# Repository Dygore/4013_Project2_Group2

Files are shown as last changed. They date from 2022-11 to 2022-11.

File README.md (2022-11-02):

# ECEN 4013 Project 2 Group 2

## About
This project is for Group 2's ECEN 4013 project 2, all of the code contained will be documented and cited if needed. The goal of this project is to create a circuit that can transmit IMU and GPS data through 3 means of communication (USB, UHF RF, and SD Card). This Github project will be used to store all of the code architecture, the details of the project are still being finalized and will be updated soon!

## Details
The current plan is to have two seperate circuits based on difficulty. The first circuit will be the main focus with the details contained below, the second circuit details have not been finalized yet.

Micro controller: Raspberry Pi Pico  
GPS: Adafruit Mini GPS PA1010D  
Radio: HC05  
IMU: Adafruit BNO055  
SD Card:  HW-125 SPI Micro SD Board  
Battery: LP103454  

## References
-https://microcontrollerslab.com/neo-6m-gps-module-raspberry-pi-pico-micropython/

Dylan Gore 10/24/2022

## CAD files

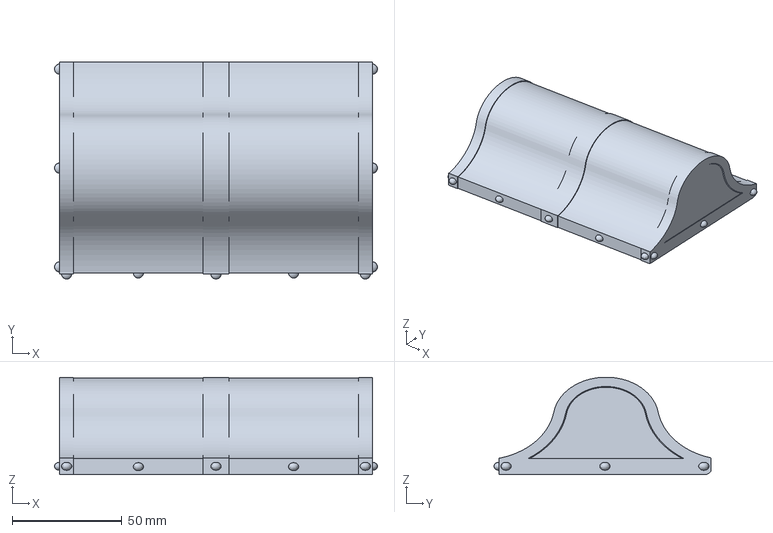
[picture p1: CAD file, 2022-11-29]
3D_Print/Top.3mf
147.3 x 99.0 x 44.5 mm

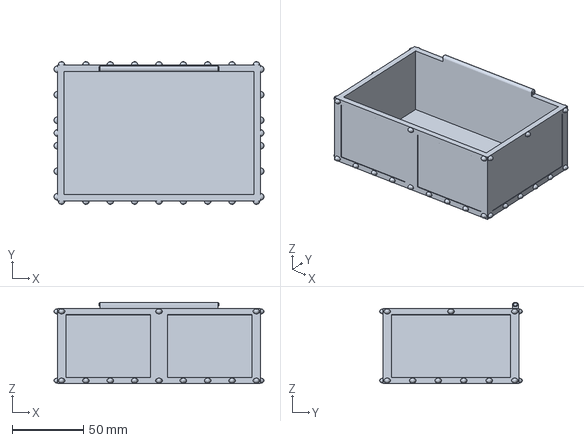
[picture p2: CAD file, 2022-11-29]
3D_Print/Body.3mf
147.3 x 100.1 x 57.1 mm

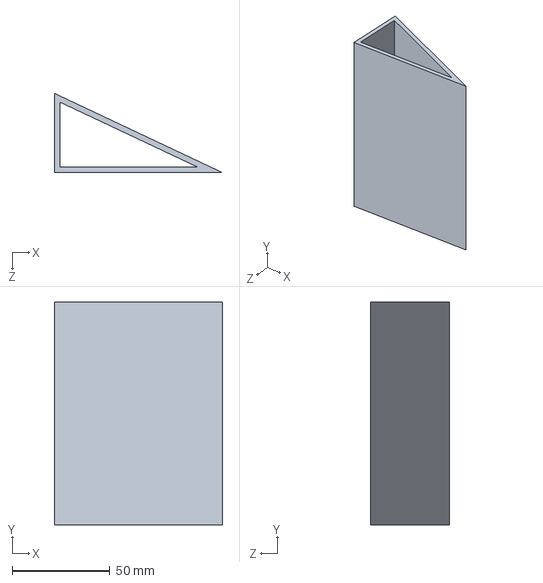
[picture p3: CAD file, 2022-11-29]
3D_Print/Triangle.SLDPRT
86.1 x 114.3 x 40.6 mm

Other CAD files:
3D_Print/Triangle.3mf

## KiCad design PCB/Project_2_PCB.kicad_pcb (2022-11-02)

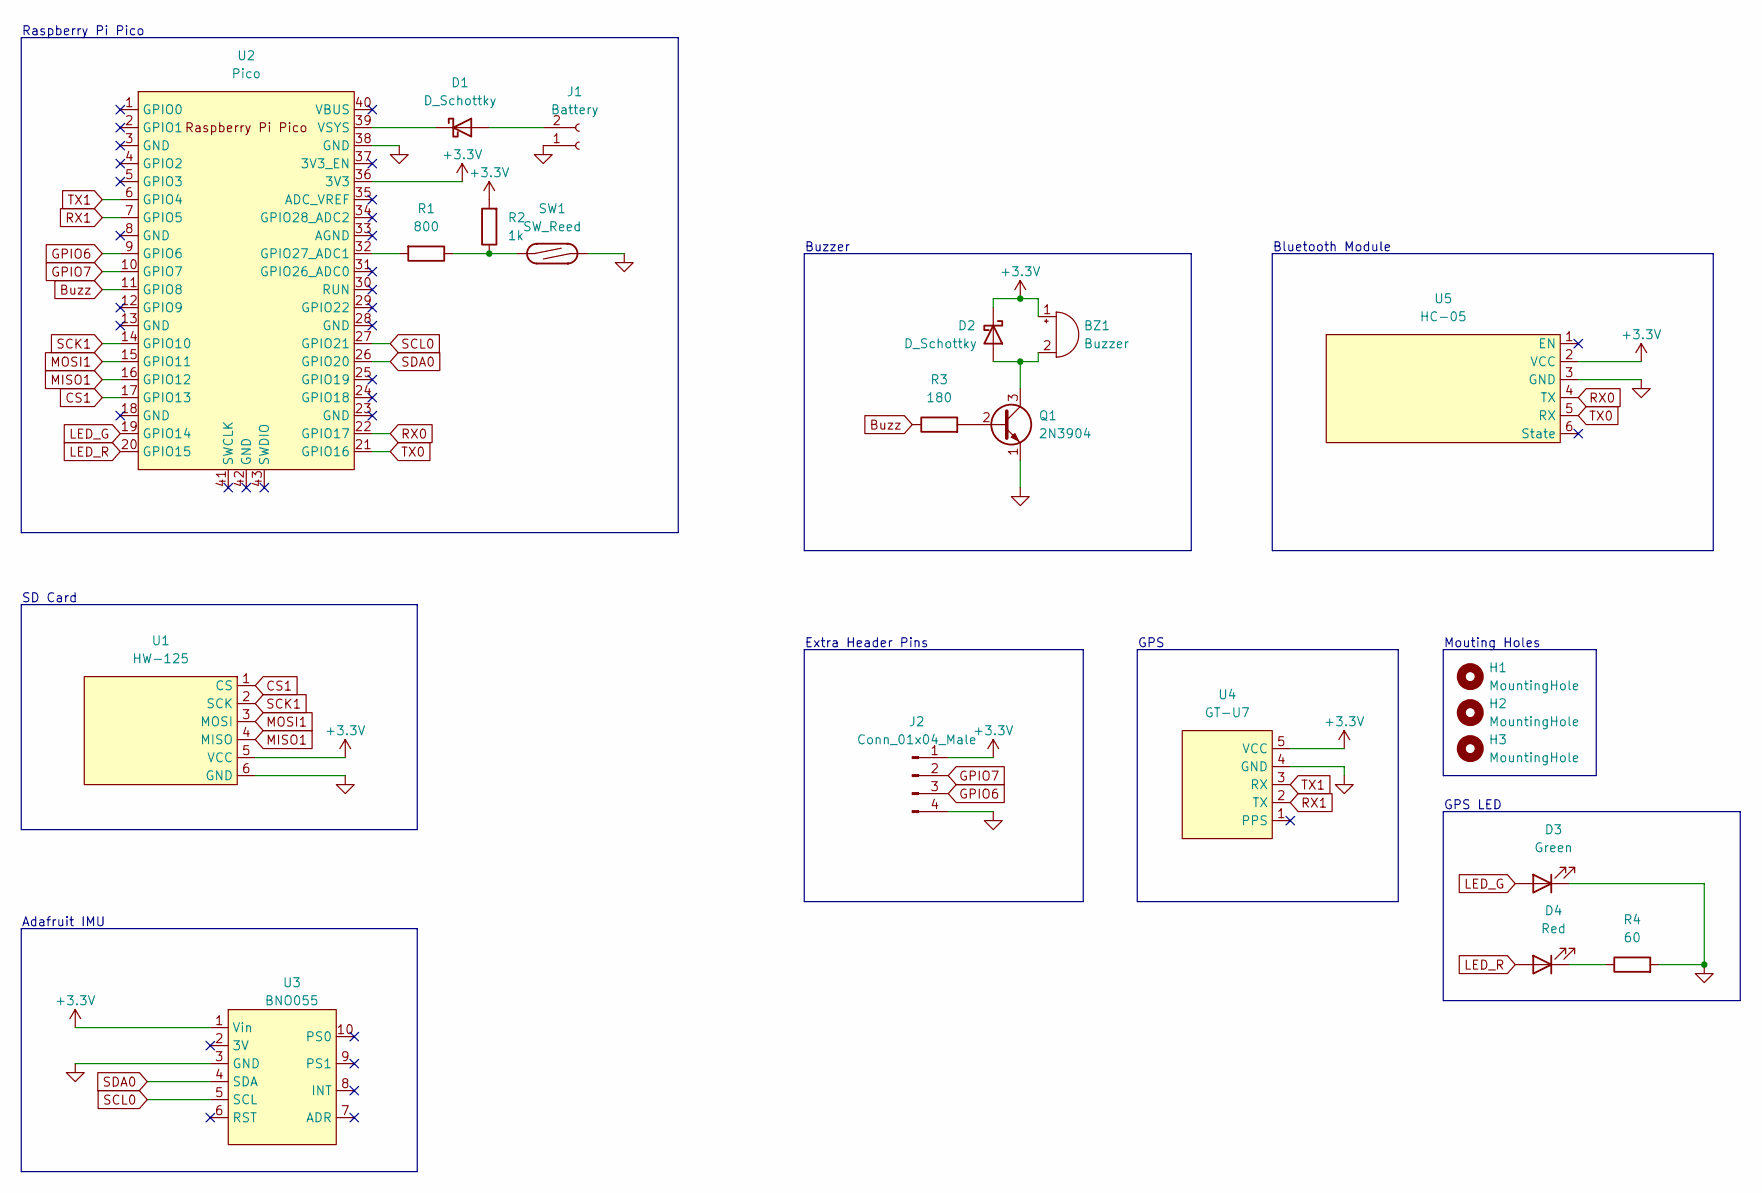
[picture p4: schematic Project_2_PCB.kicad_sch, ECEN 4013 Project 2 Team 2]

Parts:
BZ1: Buzzer; CMT8585397SMTTR
D1, D2: D_Schottky; D_1206_3216Metric
D3: Green; LED_D5.0mm
D4: Red; LED_D5.0mm
H1, H2, H3: MountingHole; MountingHole_4.3mm_M4_Pad_TopBottom
J1: Battery; JST_PH_S2B-PH-K_1x02_P2.00mm_Horizontal
J2: Conn_01x04_Male; PinHeader_1x04_P2.54mm_Vertical
Q1: 2N3904; SOT-23
R1: 800; R_Axial_DIN0207_L6.3mm_D2.5mm_P7.62mm_Horizontal
R2: 1k; R_Axial_DIN0207_L6.3mm_D2.5mm_P7.62mm_Horizontal
R3: 180; R_Axial_DIN0207_L6.3mm_D2.5mm_P7.62mm_Horizontal
R4: 60; R_Axial_DIN0207_L6.3mm_D2.5mm_P7.62mm_Horizontal
SW1: SW_Reed; R_Axial_DIN0207_L6.3mm_D2.5mm_P10.16mm_Horizontal
U1: HW-125
U2: Pico; RPi_Pico_SMD_TH
U3: BNO055
U4: GT-U7
U5: HC-05

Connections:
+3V3: BZ1.1 (-), D2.1 (K), J2.1, R2.2, U1.5 (VCC), U2.36 (3V3), U3.1 (Vin), U4.5 (VCC), U5.2 (VCC)
Buzz: R3.1, U2.11 (GPIO8)
CS1: U1.1 (CS), U2.17 (GPIO13)
GND: D3.1 (K), J1.1, J2.4, Q1.1 (E), R4.2, SW1.2, U1.6 (GND), U2.38 (GND), U3.3 (GND), U4.4 (GND), U5.3 (GND)
GPIO6: J2.3, U2.9 (GPIO6)
GPIO7: J2.2, U2.10 (GPIO7)
LED_G: D3.2 (A), U2.19 (GPIO14)
LED_R: D4.2 (A), U2.20 (GPIO15)
MISO1: U1.4 (MISO), U2.16 (GPIO12)
MOSI1: U1.3 (MOSI), U2.15 (GPIO11)
unnamed: BZ1.2 (+), D2.2 (A), Q1.3 (C)
unnamed: D1.1 (K), U2.39 (VSYS)
unnamed: D1.2 (A), J1.2
unnamed: D4.1 (K), R4.1
unnamed: Q1.2 (B), R3.2
unnamed: R1.1, R2.1, SW1.1
unnamed: R1.2, U2.32 (GPIO27_ADC1)
RX0: U2.22 (GPIO17), U5.4 (TX)
RX1: U2.7 (GPIO5), U4.2 (TX)
SCK1: U1.2 (SCK), U2.14 (GPIO10)
SCL0: U2.27 (GPIO21), U3.5 (SCL)
SDA0: U2.26 (GPIO20), U3.4 (SDA)
TX0: U2.21 (GPIO16), U5.5 (RX)
TX1: U2.6 (GPIO4), U4.3 (RX)

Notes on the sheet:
Extra Header Pins
Raspberry Pi Pico
Bluetooth Module
GPS
Adafruit IMU
Buzzer
GPS LED
Mouting Holes
SD Card

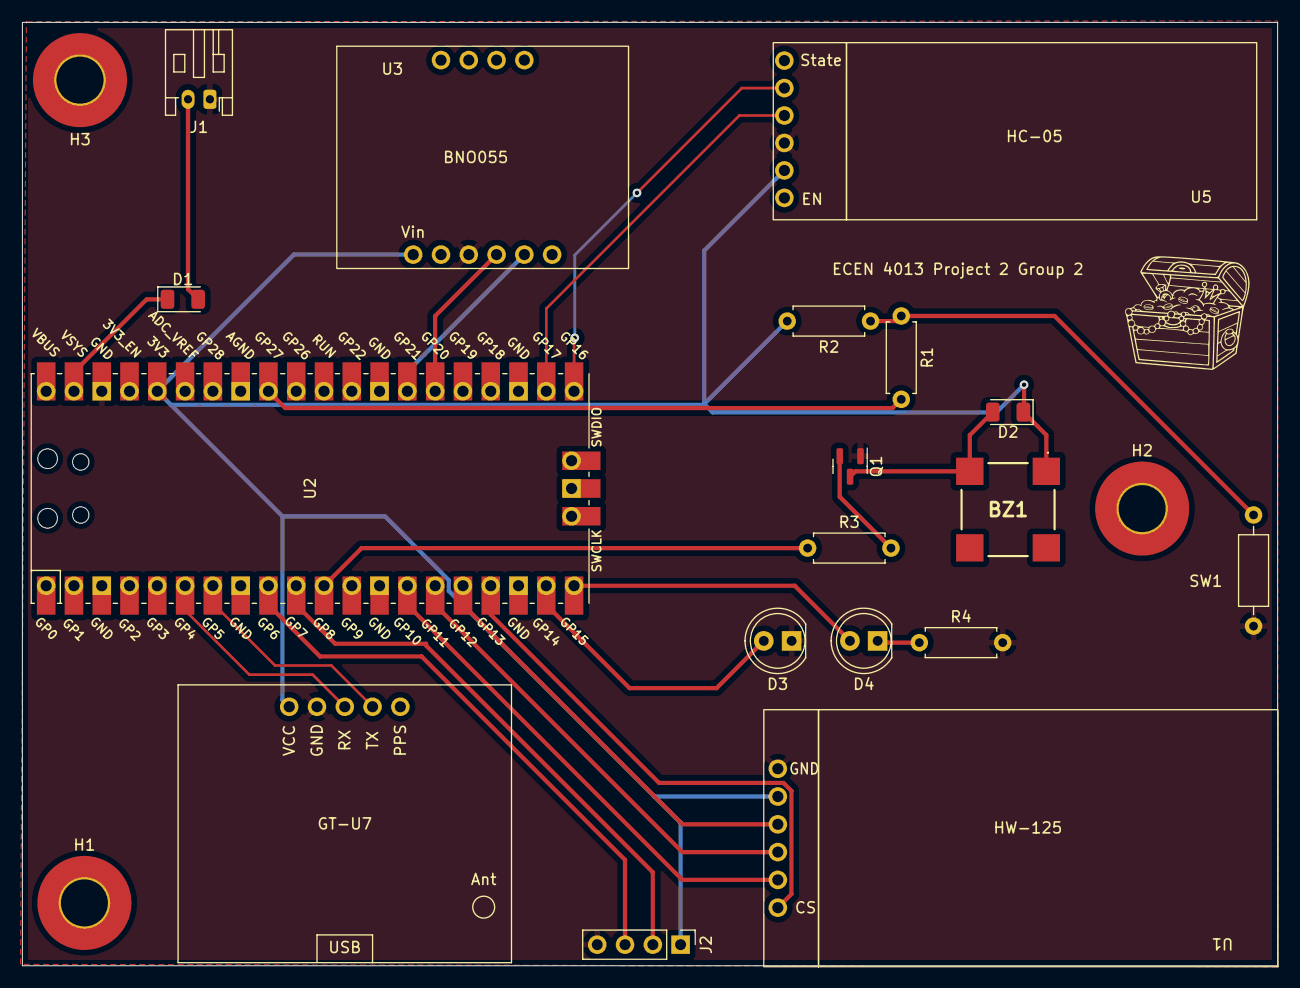
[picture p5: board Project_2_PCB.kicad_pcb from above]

Board: 2 copper layers, 114.7 x 86.2 mm, 21 parts (0 on the bottom side), 24 nets.

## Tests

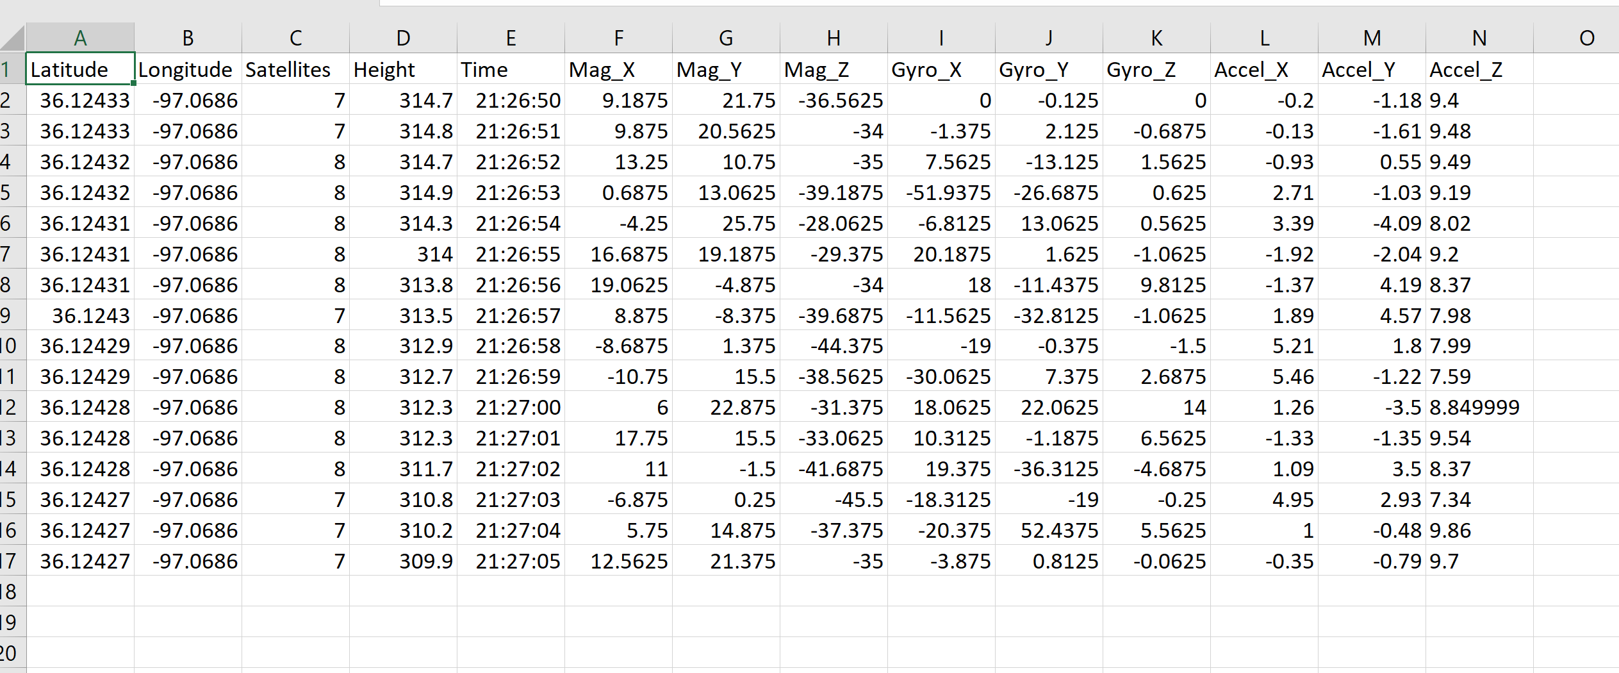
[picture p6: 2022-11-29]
Main/First_Working_GPS_IMU_Test.png

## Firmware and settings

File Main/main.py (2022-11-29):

#-------------------------------Import from Pico-------------------------------
from machine import Pin, UART, I2C, SPI, PWM

#-------------------------------Other Imports-------------------------------
import utime, time
from bno055 import *

import sdcard, uos

#-------------------------------Initialize Serial Communcation-------------------------------
#----------GPS----------
gpsModule = UART(1, baudrate=9600, tx=Pin(4), rx=Pin(5))
#----------Bluetooth UART----------
#----------IMU I2C----------
i2c = I2C(0, scl=Pin(21), sda=Pin(20))
#----------SD Card SPI----------
cs = Pin(13, Pin.OUT)
spi = SPI(1,baudrate=100000,polarity=0,phase=0,bits=8,firstbit=SPI.MSB,sck=Pin(10),mosi=Pin(11),miso=Pin(12))
#-------------------------------Variable Declarations/Initializations-------------------------------
buzzer = PWM(Pin(8))
tones = {
"B0": 31,
"C1": 33,
"CS1": 35,
"D1": 37,
"DS1": 39,
"E1": 41,
"F1": 44,
"FS1": 46,
"G1": 49,
"GS1": 52,
"A1": 55,
"AS1": 58,
"B1": 62,
"C2": 65,
"CS2": 69,
"D2": 73,
"DS2": 78,
"E2": 82,
"F2": 87,
"FS2": 93,
"G2": 98,
"GS2": 104,
"A2": 110,
"AS2": 117,
"B2": 123,
"C3": 131,
"CS3": 139,
"D3": 147,
"DS3": 156,
"E3": 165,
"F3": 175,
"FS3": 185,
"G3": 196,
"GS3": 208,
"A3": 220,
"AS3": 233,
"B3": 247,
"C4": 262,
"CS4": 277,
"D4": 294,
"DS4": 311,
"E4": 330,
"F4": 349,
"FS4": 370,
"G4": 392,
"GS4": 415,
"A4": 440,
"AS4": 466,
"B4": 494,
"C5": 523,
"CS5": 554,
"D5": 587,
"DS5": 622,
"E5": 659,
"F5": 698,
"FS5": 740,
"G5": 784,
"GS5": 831,
"A5": 880,
"AS5": 932,
"B5": 988,
"C6": 1047,
"CS6": 1109,
"D6": 1175,
"DS6": 1245,
"E6": 1319,
"F6": 1397,
"FS6": 1480,
"G6": 1568,
"GS6": 1661,
"A6": 1760,
"AS6": 1865,
"B6": 1976,
"C7": 2093,
"CS7": 2217,
"D7": 2349,
"DS7": 2489,
"E7": 2637,
"F7": 2794,
"FS7": 2960,
"G7": 3136,
"GS7": 3322,
"A7": 3520,
"AS7": 3729,
"B7": 3951,
"C8": 4186,
"CS8": 4435,
"D8": 4699,
"DS8": 4978
}

song = ["E5","D5","C5","D5","E5","E5","E5","P","D5","D5","D5","E5","G5","G5","P","E5","D5","C5","D5","E5","E5","E5","P","E5","D5","D5","E5","D5","C5"]
#----------GPS----------
buff = bytearray(255)
timeout = False
Status = False
latitude = ""
longitude = ""
satellites = ""
HeightGeo = ""
GPStime = ""
ledg = Pin(14, Pin.OUT)
ledr = Pin(15, Pin.OUT)
magnet = Pin(27, Pin.IN)
#----------Bluetooth----------
#----------IMU----------
addr = 0x28
imu = BNO055(i2c)
accel = ""
gyro= ""
mag = ""
data = []

#----------SD Card----------
while True:
    try:
        sd = sdcard.SDCard(spi, cs)

        vfs = uos.VfsFat(sd)
        uos.mount(vfs, "/sd")
        break
    except:
        ledg.value(0)
        ledr.value(1)
    
fields = ['Latitude', 'Longitude', 'Satellites', 'Height', 'Time', 'Mag_X', 'Mag_Y', 'Mag_Z', 'Gyro_X', 'Gyro_Y', 'Gyro_Z', 'Accel_X', 'Accel_Y', 'Accel_Z']
#-------------------------------Define Methods-------------------------------
#----------GPS----------
def getGPSData(gpsModule):
    global Status, latitude, longitude, satellites, GPStime, HeightGeo
    
    while True:
        #Get second line and add it to buffer
        buffer = str(gpsModule.readline())
        
        #Split up buffer using commas
        section = buffer.split(',')
    
        #We only want GPGGA as it contains all the data that is needed for this project
        if (section[0] == "b'$GPGGA" and section[4] != ''):
            latitude = convertToDegree(section[2])
            if (section[3] == 'S'):
                latitude = '-' + latitude
            longitude = convertToDegree(section[4])
            if (section[5] == 'W'):
                longitude = '-' + longitude
            satellites = section[7]
            HeightGeo = section[9]
            GPStime = section[1][0:2] + ":" + section[1][2:4] + ":" + section[1][4:6]
            Status = True
            #Set LED to Signal Found
            ledg.value(1)
            ledr.value(0)
            break
        elif (section[0] == "b'$GPGGA" and section[4] == '') :
            #Set LED to Searching for Signal
            ledg.value(0)
            ledr.value(1)    
        utime.sleep_ms(100)
        
def convertToDegree(RawDegrees):

    RawAsFloat = float(RawDegrees)
    firstdigits = int(RawAsFloat/100) 
    nexttwodigits = RawAsFloat - float(firstdigits*100) 
    
    Converted = float(firstdigits + nexttwodigits/60.0)
    Converted = '{0:.6f}'.format(Converted) 
    return str(Converted)

#----------Bluetooth----------

#----------IMU----------
def getIMUData(imu):
    global mag_tuple, gyro_tuple, accel_tuple

    mag_tuple = ",".join(str(item) for item in imu.mag())
    
    gyro_tuple = ",".join(str(item) for item in imu.gyro())

    accel_tuple = ",".join(str(item) for item in imu.accel())
    
#----------SD Card----------
def sdCard():
    global latitude, longitude, satellites, GPStime, HeightGeo, mag_tuple, gyro_tuple, accel_tuple
    while True:
        try:
            logf = open("/sd/logfile.csv","a")
            logf.write(latitude)
            logf.write(",")
            logf.write(longitude)
            logf.write(",")
            logf.write(satellites)
            logf.write(",")
            logf.write(HeightGeo)
            logf.write(",")
            logf.write(GPStime)
            logf.write(",")
            logf.write(mag_tuple)
            logf.write(",")
            logf.write(gyro_tuple)
            logf.write(",")
            logf.write(accel_tuple)
            logf.write("\r\n")
            logf.close()
            break
        except:
            ledg.value(0)
            ledr.value(1)

#----------Buzz----------
def playtone(frequency):
    buzzer.duty_u16(1000)
    buzzer.freq(frequency)

def bequiet():
    buzzer.duty_u16(0)

def playsong(mysong):
    for i in range(len(mysong)):
        if (mysong[i] == "P"):
            bequiet()
        else:
            playtone(tones[mysong[i]])
        utime.sleep_ms(300)
    bequiet()
    
#-------------------------------Main Methods-------------------------------
logf = open("/sd/logfile.csv","a")
try:
    logf.write("Latitude")
    logf.write(",")
    logf.write("Longitude")
    logf.write(",")
    logf.write("Satellites")
    logf.write(",")
    logf.write("HeightGeo")
    logf.write(",")
    logf.write("GPS Time")
    logf.write(",")
    logf.write("Mag_X")
    logf.write(",")
    logf.write("Mag_Y")
    logf.write(",")
    logf.write("Mag_Z")
    logf.write(",")
    logf.write("Gryo_X")
    logf.write(",")
    logf.write("Gyro_Y")
    logf.write(",")
    logf.write("Gyro_Z")
    logf.write(",")
    logf.write("Accel_X")
    logf.write(",")
    logf.write("Accel_Y")
    logf.write(",")
    logf.write("Accel_Z")
    logf.write("\r\n")
except OSError:
    print("Sd Full")
logf.close()

while True:
    #Get GPS Data
    getGPSData(gpsModule)
    #Get IMU Data
    getIMUData(imu)
        
    #Output to USB
    if(Status == True):
         print("{"+ latitude + ',' + longitude + ',' + satellites + ',' + HeightGeo + ',' + GPStime + ',' + mag_tuple + ',' + gyro_tuple + ',' + accel_tuple +"\n")   
         Status = False
         
    #SD Card
    sdCard()
    #Output to Bluetooth
    
    if magnet.value() == 0:
        ledg.value(0)
        ledr.value(1)
        playsong(song)
    

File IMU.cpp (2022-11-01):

#include <iostream>
#include <vector>
#include <string>
#include "hardware/i2c.h" //i2c protocol library
#include "pico/stdlib.h" //raspberry pi pico library

#define I2C_PORT i2c0; //GPIO Pins 4 and 5
static int addr = 0x28; // default adafruit address (peripheral)

// Initialize Accelerometer Function
void accel_init(void){
    //check to see that connection is correct
    //should expect the chip to have an ID of 0xA0 or 1010_0000
    sleep_ms(10000); //add short delay to help  BNO055
    uint8_t reg = 0x00;
    uint8_t chipID[1];
    i2c_write_blocking(I2C_PORT, addr, &reg, 1, true); //true: controller maintains control of I2C bus - no stop msg
    i2c_read_blocking(I2C_PORT, addr, chipID, 1, false); //false: controller releases control

    if(chipID[0] != 0xA0){
        while(1){
            printf("Chip ID Not Correct - Check Connection");
            sleep_ms(5000);
        }
    }

    // Use internal oscillator
    uint8_t data[2]; //2 unsigned 8 bit ints
    data[0] = 0x3F; //register addr we want to send
    data[1] = 0x40; //data we want to transmit
    i2c_write_blocking(I2C_PORT, addr, data, 2, true);

    // Reset all interrupt status bits
    data[0] = 0x3F;
    data[1] = 0x01;
    i2c_write_blocking(I2C_PORT, addr, data, 2, true);

    // Configure Power Mode
    data[0] = 0x3E;
    data[1] = 0x00;
    i2c_write_blocking(I2C_PORT, addr, data, 2, true);
    sleep_ms(50);

    // Defaul Axis Configuration
    data[0] = 0x41;
    data[1] = 0x24;
    i2c_write_blocking(I2C_PORT, addr, data, 2, true);

    // Default Axis Signs
    data[0] = 0x42;
    data[1] = 0x00;
    i2c_write_blocking(I2C_PORT, addr, data, 2, true);

    // Set units to m/s^2
    data[0] = 0x3B;
    data[1] = 0b0001000;
    i2c_write_blocking(I2C_PORT, addr, data, 2, true);
    sleep_ms(30);

    // Set operation to acceleration only
    data[0] = 0x3D;
    data[1] = 0x0C;
    i2c_write_blocking(I2C_PORT, addr, data, 2, true);
    sleep_ms(100);

}//end accel_init

int main(){
    //Initizalize STD I/O for printing over serial over USB interface
    stdio_init_all();

    //Configure the I2C Coms
    12c_init(I2C_PORT, 400000); //400kHz
    gpio_set_function(4, GPIO_FUNC_I2C); //SCL - GPIO 4
    gpio_set_function(5, GPIO_FUNC_I2C); //SDA - GPIO 5
    //enable pull-up resistors for SCL and SDA
    gpio_pull_up(4); 
    gpio_pull_up(5);

    //Call accelerometer initialization funct
    accel_init();

    uint8_t accel[6]; // Store data from the 6 acceleration regs
    int16_t accelX, accelY, accelZ; // combined 3 axis data
    float f_accelX, f_accelY, f_accelZ; // float type of accel data
    uint8_t val = 0x08; // start reg addr

    while(1){
        i2c_write_blocking(I2C_PORT, addr, &val, 1, true);
        i2c_read_blocking(I2C_PORT, addr, accel, 6, false);

        accelX = ((accel[1] << 8) | accel[0]);
        accelY = ((accel[3] << 8) | accel[2]);
        accelZ = ((accel[5] << 8) | accel[4]);

        f_accelX = accelX / 100.00;
        f_accelY = accelY / 100.00;
        f_accelZ = accelZ / 100.00;

        // Print to serial monitor
        printf("X: &6.2f    Y: %6.2f    Z: %6.2f\n", f_accelX, f_accelY, f_accelZ);
        sleep_ms(300);
    }

}//end main

/*
Data Output from BNO0
-Absolute Orientation - Euler Vector 100Hz
    3 axis orientation data based on a 360 degrees sphere
-Absolute Orientation - Quaterion 100Hz
    4 point quaternion output for more accurate data manipulation

-Angular Velocity Vector 100Hz - gyroscope
    3 axis of 'rotation speed' in rad/s

-Acceleration Vector 100Hz
    3 axis of acceleration (gravity + linear motion) in m/s^2
-Linear Acceleration Vector 100Hz
    3 axis of linear acceleration data (acceleration minus gravity) in m/s^2
-Gravity Vector 100Hz
    3 axis of gravitational acceleration (minus any movement) in m/s^2

-Magnetic Field Strength Vector 20Hz
    3 axis of magnetic field sensing in micro Tesla (uT)







*/

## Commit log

2022-11-01 IMU w python and cpp
2022-11-02 Add PCB Files
    [Project_2_PCB.kicad_pcb, Project_2_PCB.kicad_sch]
2022-11-02 Create PCB Folder
2022-11-02 Create IMU Folder
2022-11-02 Added PCB Files
    [Project_2_PCB.kicad_pcb, Project_2_PCB.kicad_sch]
